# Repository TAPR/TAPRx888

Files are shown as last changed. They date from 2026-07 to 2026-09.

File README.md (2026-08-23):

# TAPRX-888

A simplified, **HF-only** software-defined radio (SDR) receiver based on the
**RX-888** — with improved thermal and RF layout.

The KiCad project lives at the repository root (`TAPRX-888.kicad_pro` /
`.kicad_sch` / `.kicad_pcb`). **KiCad 10.0** is the project baseline.

## Features

- HF-only — no VHF downconverter
- Larger PCB, 6-layer
- 0603 passive components
- Improved thermal layout
- Improved RF alias filter
- RF shelving filter (bypassable)
- External reference clock input, auto-switching
- Attenuated filter-bypass injector port (used for timesync)
- Support use of a SPI boot EEPROM, with option for USB-only or SPI boot w/ USB fallback

Please see the schematic and layout documents for details.

## Core devices

| Function | Part |
|---|---|
| ADC | LTC2208 (16-bit) |
| Clock generator | Si5351 |
| USB3 controller | EZ-USB FX3 (CYUSB301x) |
| SPI boot flash | MX25L3233F |

## Mechanicals and Enclosure Design

The project ships its own mechanical package: a JLCMC split-aluminium enclosure
(88 × 38 x 100 mm) with two custom **PCB end plates** and M3 mounting hardware.

The board's exported STEP is the EE↔ME interface; CI assembles enclosure + board +
both plates into a coloured 3D model with a self-contained browser viewer
(**<https://tapr.github.io/TAPRx888/>**). See **[mechanical/README.md](mechanical/README.md)**
for the enclosure spec, plate geometry, and fit-check flow.

## Repository & workflow

The KiCad project is at the repo root. Design/PCB, mechanical, and end-plate work
happens on the **`design`** branch (one person at a time — KiCad layout files
can't be merged); docs, CI, and tooling go on **`dev-*`** branches; flow is
`design → dev → main`. See **[CONTRIBUTING.md](CONTRIBUTING.md)** for how we
collaborate and **[docs/RELEASE_STRATEGY.md](docs/RELEASE_STRATEGY.md)** for
branches, CI, and versioning.

## Releases

CI publishes version-stamped fabrication/design packages as GitHub Releases; the
`dev` `v0.x` pre-releases also bundle the end plates, the 3D enclosure assembly,
and a live viewer (**<https://tapr.github.io/TAPRx888/>**). Grab the latest from
the **[Releases page](https://github.com/TAPR/TAPRx888/releases)**; see
**[docs/RELEASE_STRATEGY.md](docs/RELEASE_STRATEGY.md)** for details.

## Documentation

- **[mechanical/README.md](mechanical/README.md)** — the enclosure & end-plate
  package (geometry, fit-check CI, 3D viewer)
- **[CONTRIBUTING.md](CONTRIBUTING.md)** — how we collaborate (the two-lane
  `design` / infra flow, the design baton)
- **[docs/RELEASE_STRATEGY.md](docs/RELEASE_STRATEGY.md)** — versioning, CI, and
  how releases are cut
- **[docs/AI_REVIEW.md](docs/AI_REVIEW.md)** — using AI review responsibly; read
  this before pointing an AI tool at the design
- **[docs/EMERGENCY_ROLLBACK.md](docs/EMERGENCY_ROLLBACK.md)** — the parachute:
  how to turn the CI/branch machinery off if it's ever too much

## Reference documents

Device datasheets (LTC2208, Si5351, EZ-USB FX3, MX25L3233F) and RX888 reference
material are on the [project wiki → Reference Documents](https://github.com/TAPR/TAPRx888/wiki/Reference-Documents).

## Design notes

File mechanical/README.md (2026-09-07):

# Mechanical — enclosure & end plates

The TAPRX-888 mechanical package: the enclosure model and the two end-plate
boards. It lives **in this repo** (not a separate one) because the plates are
mechanically coupled to the board — a connector move and its matching cutout move
land as one atomic commit and version together.

```
mechanical/
  enclosure.step    # case model — the EE↔ME interface artifact
  endplate-front/   # standalone KiCad project (front panel)
  endplate-rear/    # standalone KiCad project (rear panel)
```

## Enclosure

`enclosure.step` — the [JLCMC split aluminium box][box] (`K70-8838-H7`, 88 × 38),
**shortened 120 → 100 mm** with the **stock end plates removed** so the PCB plates
take their place. Two-piece (both clamshell halves); verified 88 × 38.02 ×
100 mm, 2 solids. The plate outline and M3 corner pattern (Ø3.4 at ±41, ±14.21
from centre) come from its end profile.

[box]: https://jlcmc.com/product/b/U01/BR9272/aluminum-box-%28jlc%29-88*38*120mm-split

Each plate is its own KiCad project (own `fp-lib-table`/`sym-lib-table`); the root
board is untouched. The plates are **non-signal PCBs** — Edge.Cuts, connector
cutouts, mounting holes, silk (labels + TAPR/HamSCI/TIS logos), plus a
script-generated **GND shield pour + stitching-via ring, grounded to the
enclosure through the M3 screws** (see *Shield pour & GND stitching* below).

## Releases

Board and plates version separately on `main` (`vX.Y` vs independent
`endplates-vX.Y`); the `dev` `v0.x` pre-release folds board + both plates + the
mechanical assembly into one snapshot. See `docs/RELEASE_STRATEGY.md`. The board's
exported **STEP** is the EE↔ME interface, published standalone as
`TAPRX-888-v<REV>.step`.

## Fit-check CI

The reusable `mechanical-build.yml` (called by `mechanical-ci` on `design`/`dev-*`
and by `dev-release` on `dev`) assembles enclosure + board + both plates
(`assemble_mechanical.py`, CadQuery) into a multi-component STEP, a coloured GLB
(`assemble_glb.py`), and a self-contained viewer (`make_3d_viewer.py`), and
deploys the viewer to **<https://tapr.github.io/TAPRx888/>**. The viewer
(three.js) lets you toggle the four top-level parts -- enclosure, main board,
front / rear end plates -- on and off (turning the translucent enclosure off is
handy for seeing the board inside). `assemble_glb.py` recolours the boards'
soldermask to the Turn Island navy (KiCad's `Blue` stackup preset exports a
brighter cornflower blue), and the viewer's lighting is tuned so every face reads
the same colour. Non-gating; board **connector** 3D models are still missing (#45).

## Plate geometry

**Starter boards, not fab-ready** — open each in KiCad 10 to confirm it parses,
then overlay onto the enclosure end to confirm J1↔J1 / J5↔J5 orientation. Full
parameters live on each board's `Cmts.User` layer; key values:

| Item | Value |
|---|---|
| Outline | 88 × 38 mm, R4.5 |
| M3 mounting holes | Ø3.4 at (±41, ±14.21); plate screws on |
| SMA `J1/J3/J2/J4` (front) | X = −27 / −9 / +9 / +26.8, Y = 7.9; Ø7.0 |
| USB `J5` (rear, X-mirrored) | X = 25.04, Y = 14.79; 12.5 × 12.7 opening |
| JTAG `J11` | internal, no cutout |

Cutout X maps the real connector position via `plate-X = 44 + (board-X − 138)`; Y
from the 7.9 mm PCB rail height above the floor.

## Shield pour & GND stitching

Each plate carries a **dual-layer GND copper pour** (F.Cu + B.Cu, the `shield`
zone) tied together by a **perimeter ring of 0.3 / 0.6 mm through-vias**, and is
**grounded to the aluminium enclosure through the M3 screws** — each mounting hole
gets a Ø7 **exposed-copper mask aperture** on both faces so the screw/washer bites
bare ENIG copper. The **front** plate additionally gets a **Ø10 copper-pour
keepout** around each SMA. Together: an EMI shield bonded front↔back and to chassis.

The plates have **no schematic** (they're generated, PCB-only), so there is no net
list to draw a net from. Instead the pour and ring are put on a **`GND` net written
straight into the board** by `scripts/stitch_perimeter.py` (name-based net, KiCad
10 `20260206` format). That shared net is what lets the pour flood **solidly onto
the ring** instead of clearing around it; KiCad keeps the injected net across load
and DRC is clean, so no stub schematic is needed.

**All of this copper is generated — do not hand-edit it.** Retune the constants at
the top of `scripts/stitch_perimeter.py` (`INSET_MM`, `PITCH_MM`, `HOLE_KEEPOUT_MM`,
`SMA_KEEPOUT_DIA_MM`, `SCREW_MASK_DIA_MM`, drill/pad) and re-run per plate:

```sh
# front (SMA keepouts + screw grounding)
python3 scripts/stitch_perimeter.py mechanical/endplate-front/endplate-front.kicad_pcb --net GND --sma-keepout --screw-mask
# rear (screw grounding; no SMAs)
python3 scripts/stitch_perimeter.py mechanical/endplate-rear/endplate-rear.kicad_pcb  --net GND --screw-mask
```

then open in KiCad, **refill zones (`B`)**, and DRC. The script is idempotent — it
strips its own previous ring / keepouts / mask apertures before placing — derives
the outline and hole classes from the board's own Edge.Cuts, and lays the ring
**symmetric about both plate centrelines**, inset from the edge and stood off the
holes.

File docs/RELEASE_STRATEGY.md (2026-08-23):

# Release Strategy

How TAPRX-888 versions, builds, and publishes. Implemented in
`.github/workflows/` (`dev-checks`, `dev-release`, `main-release`,
`endplate-release`, `mechanical-ci`, reusable `mechanical-build`) and
`scripts/next_version.sh` (offline-tested by `scripts/test_next_version.sh`).

## Branches & CI

Flow: **`design` → `dev` → `main`**, with a `ci-docs` review surface.

- **`design`** — designer's working branch (unprotected). Each push runs
  `dev-checks` and publishes results to `ci-docs`.
- **`ci-docs`** — throwaway branch holding the latest `design` check results
  (ERC/DRC/BOM + schematic PDF), readable via `raw.githubusercontent.com`; the
  reviewer reads it to decide `design → dev`.
- **`dev`** — integration + default branch; protected. A qualifying merge cuts a
  `v0.x` **pre-release**. `dev-*` feature branches also run `dev-checks`.
- **`main`** — release branch; protected, stricter gate. `dev → main` cuts a
  production revision.

Merges into `dev` and `main` are **squash** merges. Which work goes on which
branch (design/PCB/mechanical vs docs/CI) is in `CONTRIBUTING.md`.

CI lanes:

- **`dev-checks`** — on `design`/`dev-*` pushes and PRs into `dev`/`main`: ERC,
  DRC, BOM completeness + schematic PDF / gerbers artifacts; on `design`, also
  publishes to `ci-docs`.
- **`dev-release`** — on merge to `dev`: the `v0.x` combined pre-release (below).
- **`main-release`** — on merge to `main` (or dispatch): production `vX.0`.
- **`endplate-release`** — on merge to `main`: independent `endplates-vX.Y` lane.
- **`mechanical-ci`** / reusable **`mechanical-build`** — mechanical assembly +
  Pages viewer for `design`/`dev-*` (`dev` is handled by `dev-release`).

## Versioning

**`main` = production spins (whole majors); `dev` = the minors between.** `dev`'s
major follows whatever `main` last shipped.

| Event | Version |
|---|---|
| `dev` merge, pre-1.0 | `0.6 → 0.7 …` |
| first `dev → main` | **`1.0`** |
| `dev` merge, post-1.0 | `1.1 → 1.2 …` |
| next `dev → main` | **`2.0`** |

- **`main`** = `<latest main major + 1>.0` (first ever → `1.0`); always a major,
  published as a normal Release ("Latest").
- **`dev`** = minor++ in the current major line; first after a `main` `X.0` is
  `X.1`, pre-1.0 seeds at `0.6`. Published `--prerelease`. Does **not** retire at
  1.0 — it keeps running `1.x`, `2.x`, … toward the next `main`.

**GitHub Releases are the source of truth** — no version lives in the design.
Tags `v<MAJOR>.<MINOR>`; pre-releases add a `(pre-release)` title suffix. Policy
lives once in `scripts/next_version.sh`, called by both lanes.

### `dev` combined snapshot

The `dev` pre-release is a **single combined snapshot** (unlike `main`, where
board and plates ship on separate lanes). Each qualifying `dev` merge folds into
the one `v0.x` pre-release:

- the **board** package (`scripts/build_release.sh`);
- **both end-plate** packages (`scripts/build_endplates.sh`), stamped with the
  board's `v0.x` and the end-plate design commit;
- the **mechanical assembly** — STEP + coloured GLB + self-contained 3D viewer
  (reusable `mechanical-build.yml`) — and it deploys the viewer to GitHub Pages
  (<https://tapr.github.io/TAPRx888/>).

Its trigger therefore spans board ∪ end-plate ∪ mechanical inputs
(`mechanical/**`, `3d/**`, `TAPR.kicad_wks`, the `assemble_*` / `make_3d_viewer` /
`build_endplates` scripts) — any of them cuts/refreshes it. `dev` deploys Pages
here, not via `mechanical-ci`, so the two never double-deploy.

## When is a revision cut?

Both lanes publish **only when a design file changed since the last release** (of
any kind) — compared against the last release's commit, not the merge diff, so an
earlier unpublished design edit is still caught and a later docs-only merge can't
mask it. Docs/CI/script-only merges are a no-op.

**Design files:** `*.kicad_sch`, `*.kicad_pcb`, `*.kicad_pro`, `*.kicad_dru`,
`*.kicad_sym`, `Library.pretty/**`, `fp-lib-table`, `sym-lib-table`.
**Not:** `README.md`, `docs/**`, `.github/**`, `scripts/**`, `*.kicad_prl`.
(The `dev` snapshot additionally treats `mechanical/**`, `3d/**`, `TAPR.kicad_wks`
and the assembler scripts as triggers — see above.)

## Provenance (`${REVISION}`, `${GIT_HASH}`)

**Injected at build time** (`scripts/inject_provenance.py`), never committed back
— the design's committed placeholders (`DEV`/`dev`) apply only to local opens.

- `${REVISION}` — the published version, stamped into the `rev` of every sheet
  (root + `Front_End` + `refclk`) and the board.
- `${GIT_HASH}` — the **last commit that touched a design file** (not `HEAD`), so
  the mark is stable across docs-only commits.

## Release assets

Each release attaches **version-stamped** assets (the filename names its own
version). PDFs inside `…-fabrication.zip` are stamped too.

| Asset (`v<REV>`) | Contents |
|---|---|
| `TAPRX-888-v<REV>-schematic.pdf` | Schematic |
| `TAPRX-888-v<REV>-assembly.pdf` | Assembly drawing (top + bottom, framed) |
| `TAPRX-888-v<REV>.step` | Board STEP — the EE↔ME interface |
| `TAPRX-888-v<REV>-gerbers.zip` | Gerbers + drill (JLCPCB-ready) |
| `TAPRX-888-v<REV>-fabrication.zip` | Full package: gerbers, drill, LCSC BOM, CPL, iBOM, PDFs, board STEP, stamped `VERSION.txt` |

> No fixed `releases/latest/download/<name>` path (version is in the filename) —
> link to the release page. Board STEP + 3D renders ship (models vendored in
> `3d/`, resolved via `KICAD10_3DMODEL_DIR`); board **connector** models are still
> absent (issue #45), so those parts are missing from the STEP/renders.

## End-plate lane (independent, `main`)

The end plates (`mechanical/endplate-{front,rear}`) release independently via
`endplate-release.yml` — a plate change never moves the board's `vX.Y`, or vice
versa.

- **Trigger:** on merge to `main`; publishes only when a plate dir or the shared
  `TAPR.kicad_wks` changed since the last endplates release.
- **Version:** both plates cut together; tags `endplates-v<MAJOR>.<MINOR>`, minor
  auto-increments (never rolls over), first → `endplates-v1.0`; major via dispatch
  `version:`. Numbered inline, separate from the board.
- **Build:** `scripts/build_endplates.sh` stamps provenance (empty `--sheets`,
  PCB-only) and exports per plate `endplate-<front|rear>-v<REV>-gerbers.zip` +
  `-fab.pdf`. No BOM/CPL (no components).

## Manual operation (board lanes)

`main-release` / `dev-release` take `workflow_dispatch` inputs — no YAML edits:

```sh
gh workflow run main-release.yml --ref main -f version=2.5   # force a number
gh workflow run main-release.yml --ref main -f dry_run=true  # build only, no publish
```

- **`version`** — force a number; blank = automatic. Re-running an existing
  version is **idempotent** (`gh release upload --clobber`) — the "re-publish /
  fix a release" button.
- **`dry_run: true`** — builds the full package as run artifacts
  (`release-package`), forces a build even with no design change, publishes
  nothing.
- **PR preview:** every PR into `dev`/`main` touching the design or pipeline runs
  a **forced dry-run** — download `release-package` from the PR's Checks tab. The
  `release` job is gated on `publish==true` (never set for PRs).
- **Approval gate (optional):** create an Environment `release` with a required
  reviewer and uncomment `environment: release` on the `release` job.

> The **Run workflow** button only appears once the workflow is on the default
> branch (`dev`); until then the PR preview validates the pipeline.

## Edge cases

- **First production release:** no prior non-prerelease → `v1.0` (always publishes).
- **`dev` after a `main` release:** major follows `main`, so the first pre-release
  after `1.0` is `1.1` (not `0.x`/`2.0`).
- **Doc-only merge, or `main` merge with no design change:** no-op on either lane.

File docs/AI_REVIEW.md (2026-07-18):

# Using AI review on this project

This project welcomes AI-assisted review (Claude and similar). It can be
genuinely useful. It can also confidently invent problems that don't exist and
waste everyone's time — that has already happened once on this board. This file
exists so that anyone using an AI reviewer here does it the way that helps, not
the way that misleads.

Read this before pasting the design into any AI tool and reporting what it says.

## The core rule: a finding is a lead, never a verdict

An AI model will state things about this design with total confidence, including
things that are wrong. Its sense of the netlist — what's actually wired to what —
is weak unless it has been carefully grounded first (see below). It also tends to
tell you what sounds alarming or what flatters your question.

So: treat every AI finding as a **lead to check against the real design**, not as
a result. Nothing an AI says gets reported to the team as a problem, and nothing
gets acted on, until it's been verified against the current schematic/PCB and the
closed issues. This is the same "validate findings before acting" rule in
`CONTRIBUTING.md` — it applies double to AI output.

If you can't personally verify a finding, say so when you report it: "the model
flagged X, I haven't confirmed it" — don't pass it on as fact.

## Ground the model before you trust a single word

The near-miss on this board (an AI "conclusively" reporting the FX3 power/ground
was inverted — it wasn't) happened because the model was reasoning without the
reference material. Before you ask an AI anything design-level, give it, in this
order:

1. **The datasheets** — LTC2208 (ADC), Si5351 (clock), EZ-USB FX3 / CYUSB301x
   (USB3 controller), MX25L3233F (SPI flash). On the project wiki → Reference
   Documents.
2. **The reference schematic** — the FX3 SuperSpeed Explorer Kit page and
   Infineon AN70707 (FX3 hardware design guidelines / schematic checklist). Much
   of what an ungrounded model "finds" is answered directly by these.
3. **The firmware** — https://github.com/ringof/rx888-firmware — for anything
   about how the parts are actually driven (clocking, I2C, boot).
4. **The current design** — the schematic/PCB from the repo, and
5. **The closed issues** —
   https://github.com/TAPR/TAPRx888/issues?q=is%3Aissue+state%3Aclosed Closed
   issues are already-fixed items. An ungrounded model will "rediscover" them as
   new problems. Always check a finding against the closed list first.

An AI that hasn't been given these is not reviewing the board — it's guessing
about a board.

## How to actually run a useful review (the method)

This is roughly the workflow that has produced good results here:

1. **Prime it** with the material above — datasheets, design intent, firmware,
   and the combined netlist/schematic — before asking for findings.
2. **Expect the first pass to be poor and challenge it.** Don't accept the
   opening answer; push back, ask it to trace the actual net, ask how it knows.
3. **Distill.** Its raw output is feedstock, not conclusions. Pull out the claims
   worth checking, verify each against the real design and the closed issues, and
   only then do you have something worth a team issue.
4. **File verified findings as normal issues** — one item each, "clear is kind,"
   with the datasheet/appnote link that backs it (see `CONTRIBUTING.md`). File
   them as your findings that you've checked, not as "the AI said."

## For newcomers specifically

If you're new here and excited to point an AI at the design: great, but please —
its confident tone is not evidence. The failure mode is not subtle and it has
already cost this project real review cycles. A model with the datasheets and the
closed-issue list is a helpful second set of eyes. A model without them will
generate authoritative-sounding, worrying, wrong reports. The difference is
entirely in the grounding you give it and the checking you do after. Do both, or
don't report the output.

## What AI is genuinely good for here

Not to be all warnings — it's real help when grounded: sanity-checking pinouts
against a datasheet you've also handed it, drafting issue text, cross-referencing
an app-note requirement, explaining an unfamiliar part of the FX3 boot flow,
generating BOM/tooling scripts. The pattern that works is "help me check a
specific thing I can then verify," not "tell me what's wrong with this board."

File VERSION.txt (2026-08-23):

TAPRX-888  —  HF-only SDR receiver (RX-888 derivative)

Version:  development snapshot

This file names the version of the SOURCE PROJECT in this folder, so a copy
passed around as a .zip is never anonymous. The working tree is always a
development snapshot — released fabrication packages carry their exact version
on this line instead (stamped at build time).

The authoritative, fabricated revisions — each stamped with its commit hash on
the bottom silkscreen and in every exported PDF — are published here:

    https://github.com/TAPR/TAPRx888/releases

Versioning: production releases are whole majors (v1.0, v2.0, ...); v0.x and the
minor increments between majors are dev pre-releases.  See docs/RELEASE_STRATEGY.md.

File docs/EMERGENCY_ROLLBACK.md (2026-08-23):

# Emergency Rollback — read this first

The parachute. Turns off the CI/branch machinery and returns the repo to a plain
"one branch, push whenever" state. You can do all of this yourself — no waiting.

---

## READ THIS ONE LINE BEFORE YOU PULL THE CORD

**Do not roll back in the middle of a release.**

Between "cut a release" and "the boards / ADCs are actually ordered," the CI
fabrication gate is the only thing checking the package the money rides on.
Rolling back in that window removes that check. If you're in a release cycle and
something's on fire, **stop and call David** instead.

Any other time — normal design work, general frustration — roll back freely.
Nothing below is destructive to the design; schematic, PCB, libraries, and full
Git history are all preserved either way.

---

## The rollback is two steps, in two different places

Part of the "off switch" is a **file** in the repo, part is a **repo setting** on
GitHub. Deleting the file doesn't fully do it — that's expected.

### Step 1 — Stop CI (delete one folder). Anyone can do this.

Delete the `.github/workflows` folder and commit.

- GitHub Desktop: delete the folder locally, commit "Disable CI", push.
- github.com: open `.github/workflows`, delete each file, commit.

The moment that folder is gone, **CI stops running** — no more ERC/DRC/BOM checks,
no generated documents. Design files untouched.

> If a push to `design` or `dev` still kicks off a run afterward, that branch
> still carries its own copy of `.github/workflows`. To remove it from every
> branch at once, see the workflow-deletion steps in `docs/TAPR_manual_mode.md`.

If all you wanted was to make the automation stop, **you're done here.**

### Step 2 — Return to "push straight to main" (remove branch protection). Admin only.

Branch protection is a **repo setting**, not a file, so Step 1 doesn't remove it.
While protection is on you still can't push directly to `main` or `dev`.

1. **Settings → Branches** (in the TAPR/TAPRx888 repo).
2. Under "Branch protection rules," find the **`main`** rule → trash/delete → confirm.
3. Same for the **`dev`** rule.

Direct pushes to `main` work again. You can now treat `main` as the only branch
and ignore `dev` and `design`.

George has admin and can do this. David can help — a ~5-minute call — but you
don't need to wait on anyone.

---

## What this does NOT do (on purpose)

- Does **not** delete any branches, design files, or history. `dev` and `design`
  still exist; you just aren't forced through them.
- Does **not** tell you how to set the structure back up. Rebuilding CI + branch
  protection is the fiddly part — do it deliberately, together with David, not as
  an emergency.

---

## One-paragraph summary

CI machinery = the `.github/workflows` folder; delete it, CI stops. Branch
protection = a setting under Settings → Branches; remove the `main` and `dev`
rules and you're back to pushing straight to `main`. Safe anytime **except
mid-release**, where you call David instead. Nothing here touches the design or
its history.

---

## Related

- **Keep the branches, run checks/releases by hand:** `docs/TAPR_manual_mode.md`.
- **Undo the whole migration:** `docs/TAPR_rollback.md`.

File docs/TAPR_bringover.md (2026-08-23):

# TAPR bring-over runbook — migrating ringof's work into TAPR

**Purpose.** The forward migration, mirror of `docs/TAPR_rollback.md`. Brings
ringof's flattened design + CI/versioning/docs onto **TAPR/TAPRx888** as the
canonical repo via the **replay-on-top-of-`c01bece8`** model: one migration
commit, `main` advances by **fast-forward** (no force-push), `c01bece8` stays a
real ancestor so rollback is trivial.

Cross-refs: `docs/TAPR_rollback.md` (undo), `docs/TAPR_manual_mode.md`
(de-automate but keep the flow).

---

## What we're bringing, and why it's safe

- **Design is materially identical.** TAPR's `c01bece8` and ringof's `dev` share
  ancestor `3fb7ab5`; the design files (`.kicad_pcb/.sch/.pro`) differ by only
  ~5–9 lines each — ringof's provenance edits (silkscreen / `REPO` / rev), not
  electrical change.
- **ringof fixes the folder mess.** `c01bece8` still carries the old
  `TAPRX-888 KiCad/` **and** `TAPRX-888 KiCad - Copy/` duplicate directories;
  ringof's tree is **flattened to the repo root** and adds CI, scripts, docs.
- **Histories diverge**, so this is not a merge — replay ringof's tree as one
  commit whose parent is `c01bece8`.

## Readiness (already true on ringof `dev`)

- **Tree is TAPR-ready — no content edits at migration time.** De-ringofed
  (`REPO` → `github.com/TAPR/TAPRx888`, wiki/release links → TAPR); workflows use
  `${GITHUB_REPOSITORY}`; `VERSION.txt` de-numbered. The only literal "ringof"
  strings left are in these runbook docs.
- **CI is proven** green end-to-end in ringof.

---

## Settled decisions

1. **First `v1.0` is deferred — the migration is quiet.** Releases are per-repo,
   so TAPR starts with zero. Leaving Actions on while seeding would auto-cut a
   `v0.6` pre-release (first `dev` push) and a `v1.0` (first `main` push), so
   **seed with Actions disabled** (step 1); cut the first real `v1.0` later
   (step 8).
2. **Legacy PRs #4 and #30 are already closed.** Their `refs/pull/{4,30}/head`
   refs linger but are harmless — they target the pre-flatten `main` and stay
   closed.

---

## Repo settings to set on TAPR (once)

- **Settings → Actions → General → Workflow permissions → Read and write.** The
  `ci-docs` publish step and release jobs push via the built-in `GITHUB_TOKEN`;
  the default read-only token would fail them. No external secrets needed.

---

## Dry-run rehearsal (do it once, in a throwaway repo)

Rehearses the **seeding sequence** against a `c01bece8`-shaped repo.

```sh
# 1. Create an empty scratch repo (GitHub UI, or: gh repo create you/tapr-mige --private)
git remote add scratch https://github.com/<you>/tapr-mige.git
# 2. Seed it with TAPR's current state:
git push scratch tapr/main:main
# 3. Run steps 0–7 below against 'scratch' instead of 'tapr'. Watch dev-checks go
#    green, ci-docs populate, and (optionally) a release cut. Then test the
#    rollback runbook against it.
# 4. Delete the scratch repo when satisfied.
```

---

## The live bring-over

Work from a local clone with **both** remotes:

```sh
git remote -v      # origin -> ringof/TAPRx888 ; tapr -> TAPR/TAPRx888
git fetch tapr origin --tags
```

### 0. Anchor first — the restore point (see TAPR_rollback.md, step zero)

```sh
TAG="pre-migration-$(date +%Y-%m-%d)"
git tag -a "$TAG" tapr/main -m "TAPR state before the ringof bring-over"
git push tapr "$TAG"
git push tapr tapr/main:refs/heads/pre-migration    # human-friendly restore branch
```

### 1. Disable Actions (so seeding pushes don't fire CI / cut releases)

Settings → Actions → General → **Disable actions**. Re-enabled in step 6.

### 2. Build the migration commit (tree = ringof `dev`, parent = `c01bece8`)

```sh
MIG=$(git commit-tree "$(git rev-parse origin/dev^{tree})" -p tapr/main \
      -m "Bring over ringof: flatten to repo root; add CI, versioning, docs")
git branch -f dev "$MIG"
git diff --quiet origin/dev dev && echo "dev tree == ringof/dev ✓"
```

Working-tree equivalent, if you prefer:

```sh
git checkout -B dev tapr/main
git rm -rq .
git checkout origin/dev -- .
git commit -m "Bring over ringof: flatten to repo root; add CI, versioning, docs"
```

### 3. Push the branches to TAPR

```sh
git push tapr dev:dev       # new branch
git push tapr dev:main      # FAST-FORWARD c01bece8 -> migration commit (no --force)
git push tapr dev:design    # new branch (the designer's working branch)
```

(`ci-docs` is created automatically by the first `design`-push CI run — do not
seed it by hand.)

### 4. Set the default branch

Settings → General → **Default branch → `dev`**.

### 5. Turn on branch protection

- **`dev`** — require a PR; block force-push and deletion.
- **`main`** — same, as the stricter release gate.
- **`design`** — **no protection**.

(Added *after* the seeding pushes so it doesn't block them.)

### 6. Re-enable Actions

Settings → Actions → General → enable. Nothing fires from this alone: seeding
happened with Actions off, and all branches sit at the migration commit.

### 7. Smoke test — prove the live flow, low-stakes

Push a trivial **non-design** change (e.g. a doc typo) to `design`:

```sh
git switch design && git pull
# edit any doc
git commit -am "smoke test: confirm CI on TAPR" && git push
```

Confirm: `dev-checks` runs **green**, and **`ci-docs`** is created with the review
set (`erc.rpt`, `drc.rpt`, `bom.csv`, `bom_check.txt`, schematic PDF). No release
is cut (not a design file).

### 8. First real release — when the team is ready (deliberate)

Merge `design → dev` for the first pre-release, then `dev → main` (or dispatch
`main-release`) for **`v1.0`** production. See `docs/RELEASE_STRATEGY.md`.

---

## Verification — TAPR is migrated

- **Branches:** `main`, `dev`, `design`, `ci-docs` (+ `pre-migration` anchor,
  + any surviving PR refs).
- `git fetch tapr && git diff --quiet origin/dev tapr/dev && echo "dev == ringof/dev ✓"`
- **`main` is a fast-forward child of the restore point:**
  `git merge-base --is-ancestor c01bece8 tapr/main && echo "c01bece8 is an ancestor ✓"`
- **Default branch** = `dev`; **protection** = dev+main protected, design open.
- **Actions** green; **`ci-docs`** populated.

## If it goes wrong

Use `docs/TAPR_rollback.md`. Because `main` only **fast-forwarded**, the reverse
is clean: reset `main` back to the `pre-migration` anchor and delete
`dev` / `design` / `ci-docs`.

---

## Why this order

- **Anchor before touching anything** → pre-migration state is unloseable.
- **Actions off during seeding** → no surprise `v0.6`/`v1.0` from seed pushes.
- **Protection after the pushes** → protection would otherwise block seeding.
- **`main` by fast-forward, not force** → history stays continuous, rollback stays
  a one-liner.

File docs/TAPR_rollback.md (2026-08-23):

# TAPR rollback runbook — undoing the ringof bring-over

**Purpose.** The bring-over restructures **TAPR/TAPRx888**: moves `main`, adds
`dev`, `design`, `ci-docs`, installs CI workflows, turns on branch protection.
This runbook restores TAPR to its **exact pre-migration state**.

> **This doc lives in ringof on purpose.** Rolling TAPR back deletes any copy
> stored on TAPR itself; ringof keeps the whole history (and the ability to retry).

---

## The restore point

Before the bring-over, TAPR is a **single-branch repo**:

```
tapr/main → c01bece8f9f490c37a96d8cb2675cc290c8f881a   ("proper update")
```

- No `dev`, `design`, or `ci-docs` branches.
- No CI workflows, no GitHub Releases, no version tags.
- Two open pull requests (**#4**, **#30**) predate the migration; neither
  bring-over nor rollback touches them.

Captured with `git ls-remote https://github.com/TAPR/TAPRx888` on 2026-07-18.
Re-confirm the SHA before relying on it — if `main` has moved, the current tip is
the real restore point and the anchor below must be re-cut.

---

## Step zero — anchor BEFORE the bring-over (always do this first)

The migration's very first action, *before any branch is moved*, is to make the
current state unloseable. A tagged commit is immutable and never GC'd, so the
pre-migration state is always one reset away.

```sh
# From a local clone that has the TAPR remote (here called "tapr"):
git fetch tapr
TAG="pre-migration-$(date +%Y-%m-%d)"          # e.g. pre-migration-2026-07-18
git tag -a "$TAG" c01bece8 -m "TAPR state before the ringof CI/branch bring-over"
git push tapr "$TAG"

# Recommended: also a human-friendly restore BRANCH at the same commit.
git push tapr c01bece8:refs/heads/pre-migration
```

Record once done:

- Anchor tag: `pre-migration-YYYY-MM-DD` → `c01bece8…`
- Anchor branch: `pre-migration` → `c01bece8…`

---

## The reverse procedure

Run **only** if TAPR abandons the workflow. Every destructive step needs TAPR
admin. Do them in order.

### 1. Lift branch protection

Settings → **Branches / Rulesets** → disable or delete the rules on `dev` and
`main`. A protected branch cannot be force-moved or deleted, so this comes first.

### 2. Reset `main` to the restore point

```sh
git fetch tapr
git push --force tapr pre-migration:main        # from the anchor branch
# or, equivalently, straight from the SHA:
# git push --force tapr c01bece8:main
```

Verify: `git ls-remote tapr refs/heads/main` → `c01bece8…`.

### 3. Delete the branches the bring-over added

```sh
git push tapr --delete dev design ci-docs
```

(If a CLI delete is blocked, do it from the GitHub UI: **Branches → trash icon**.)

### 4. Confirm CI and protection are gone

- Resetting `main` to `c01bece8` removes the workflow files (absent in that
  commit), so **Actions** shows no workflows once `design`/`dev` are also gone.
- Delete any remaining branch-protection rules from the trial.
- Keep the `pre-migration` tag/branch if a retry is possible.

### 5. Purge trial artifacts (Releases + their tags)

The trial cuts board releases (`v0.x` pre-releases, `v1.0` if production was cut)
**and** independent end-plate releases (`endplates-vX.Y`, published on `main` by
`endplate-release.yml`). Remove both for a clean slate:

```sh
gh release list --repo TAPR/TAPRx888
# Board releases (delete the tag too):
gh release delete v0.6 --repo TAPR/TAPRx888 --cleanup-tag --yes
# repeat for v0.7, v0.8, …, and v1.0 if present
# End-plate releases:
gh release delete endplates-v1.0 --repo TAPR/TAPRx888 --cleanup-tag --yes
# repeat for every endplates-v* release/tag
```

(Or **Releases** page → each release → **Delete**, then delete leftover tags
under **Tags** — including any `endplates-v*`.)

---

## Verification — TAPR is back where it started

- `git ls-remote tapr` shows only: `main = c01bece8…`, the open PR refs (#4,
  #30), and — if kept — the `pre-migration` anchor. No `dev` / `design` / `ci-docs`.
- **Actions** tab: no workflows.
- **Releases**: none from the trial (no `v*` and no `endplates-v*`).
- `git fetch tapr && git diff c01bece8 tapr/main` → **empty**.

---

## What rollback does NOT undo

- **Clones/forks made during the trial** keep their copies.
- **ringof is untouched** — a second attempt is possible.
- **Open PRs #4 and #30** are left as they were.

---

## Retrying later

A second attempt is just re-running the bring-over from ringof. **Re-cut a fresh
`pre-migration-<date>` anchor first** (Step zero) — the SHA differs if TAPR's
`main` moved.

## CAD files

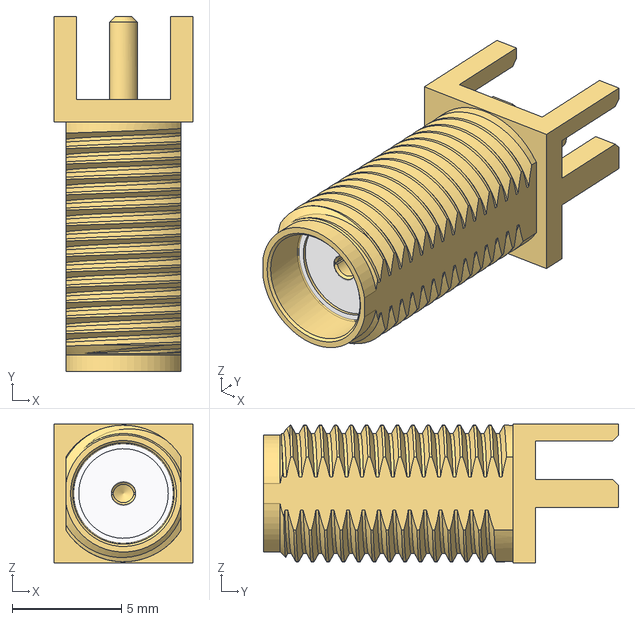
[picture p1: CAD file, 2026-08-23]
3d/SMA_Jack_EdgeMount_JLC.step
6.35 x 16.3 x 6.35 mm

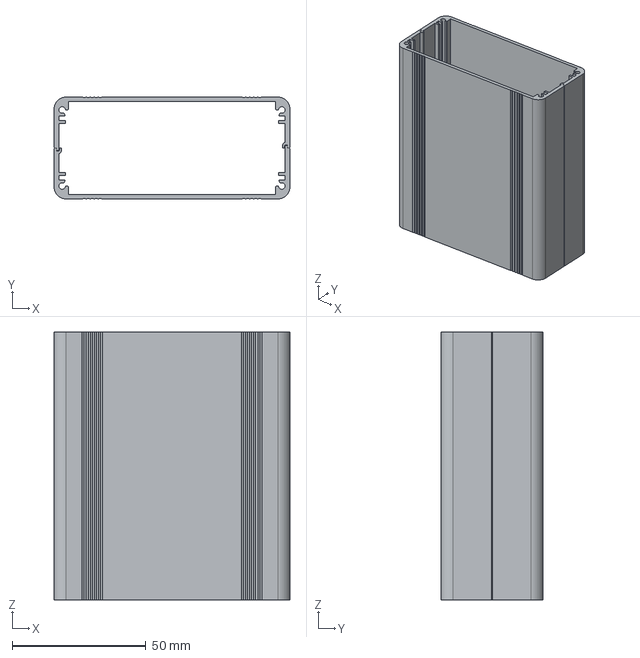
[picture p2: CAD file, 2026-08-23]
mechanical/enclosure.step
88.0 x 38.0 x 100.0 mm
enclosure_100mm_extrusion_1
enclosure_100mm_extrusion_2

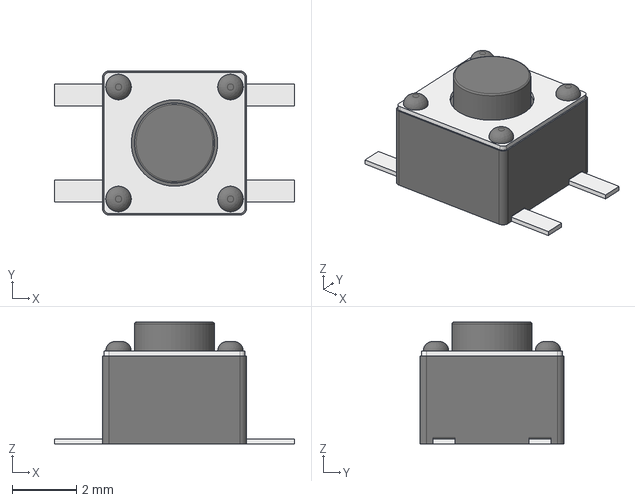
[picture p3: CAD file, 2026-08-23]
3d/BUTTON-4p5X4p5.step
7.50 x 4.50 x 3.80 mm
housing
pins x 4

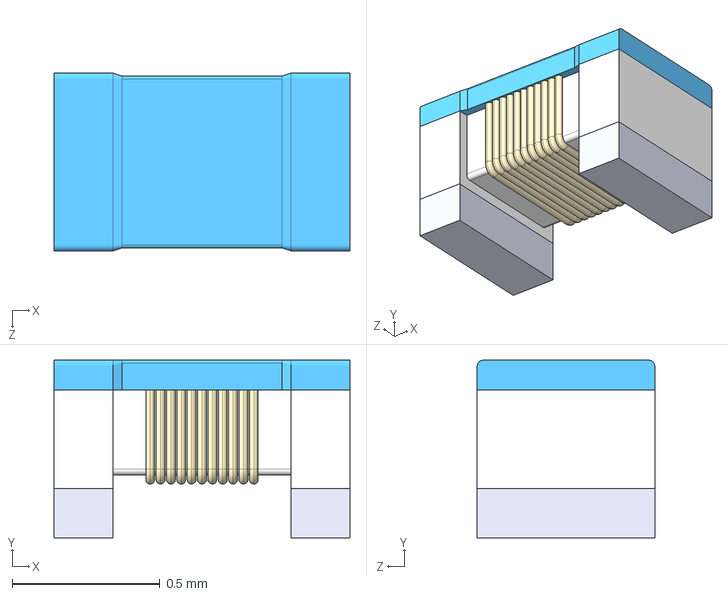
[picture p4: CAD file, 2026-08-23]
3d/Murata2U.step
1.00 x 0.6 x 0.6 mm

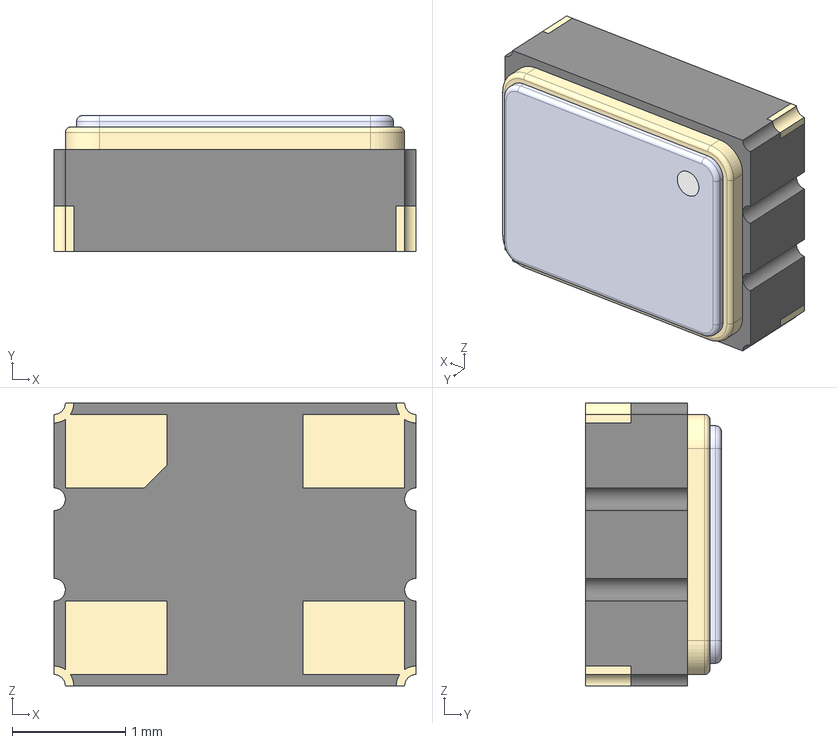
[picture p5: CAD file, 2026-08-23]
3d/TCXO-3225.step
3.20 x 1.20 x 2.50 mm
TCXO-3225-001
TCXO-3225-002
TCXO-3225-003
TCXO-3225-004
TCXO-3225-005
TCXO-3225-006
TCXO-3225-007
TCXO-3225-008
TCXO-3225-009

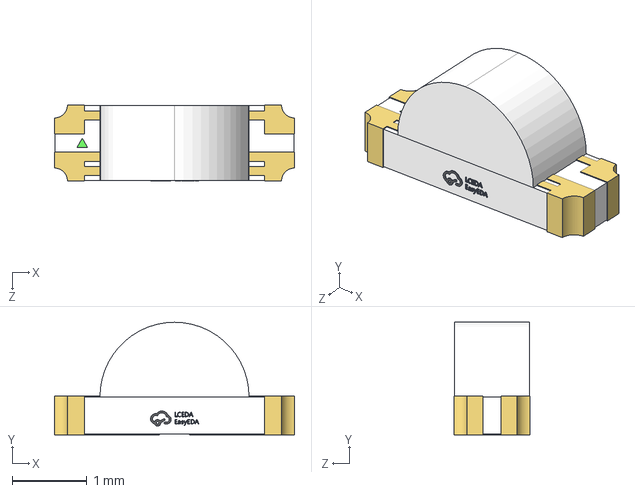
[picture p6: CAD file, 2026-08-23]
3d/LED_RGB_SIDE.step
3.22 x 1.51 x 1.02 mm

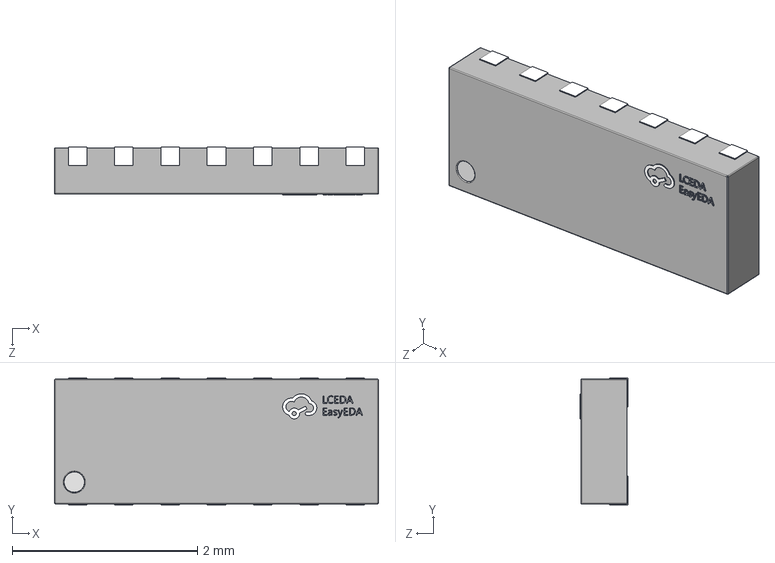
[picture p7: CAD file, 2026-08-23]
3d/SP3011.step
3.50 x 1.37 x 0.52 mm

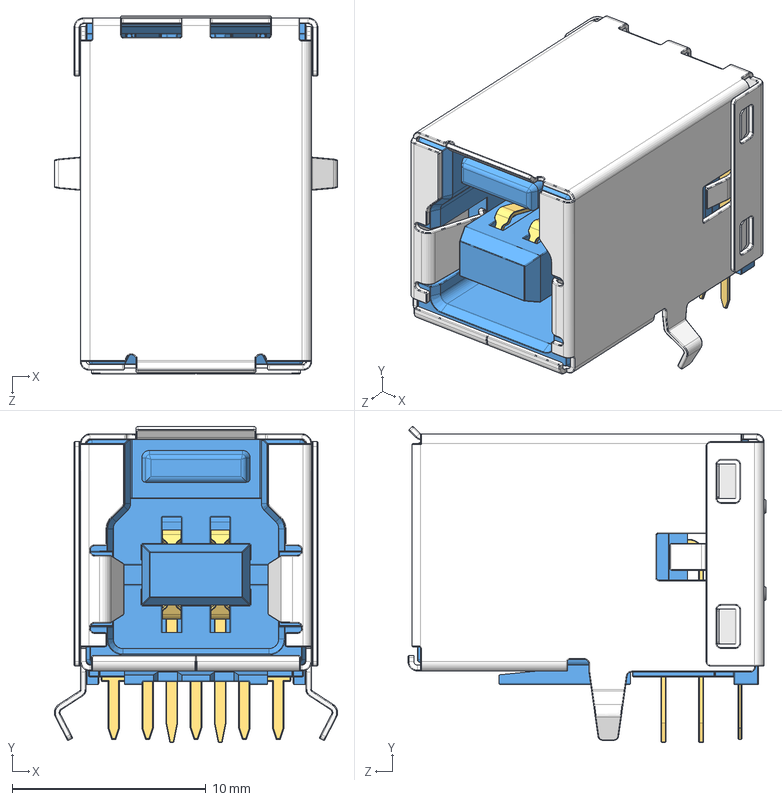
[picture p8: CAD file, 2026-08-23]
3d/USB-3.0.step
14.6 x 16.3 x 18.5 mm
inside main_ﾄｬﾈﾏｨｨ_
lower part_ﾄｬﾈﾏｨｨ_
Pin11_默认è_ x 2
Pin12_默认è_ x 2
top part_默认è_
Pin21_默认è_
out layer_ﾄｬﾈﾏｨｨ_

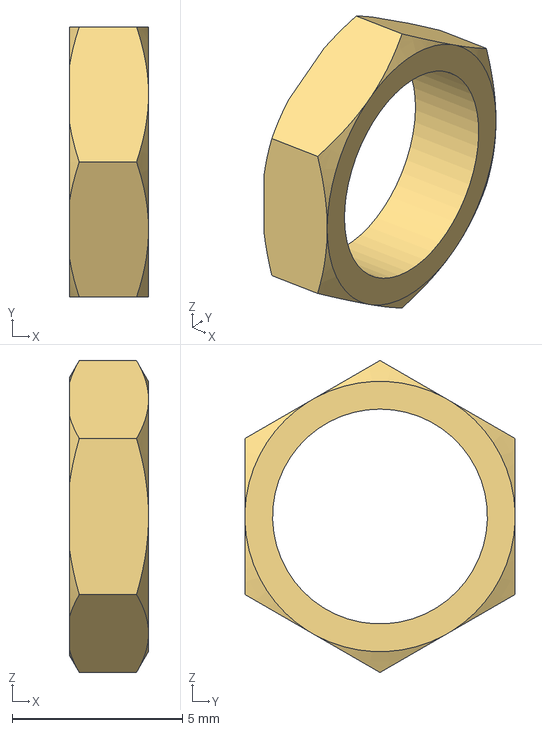
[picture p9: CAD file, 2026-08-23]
mechanical/hardware/nut.step
2.32 x 7.92 x 9.15 mm

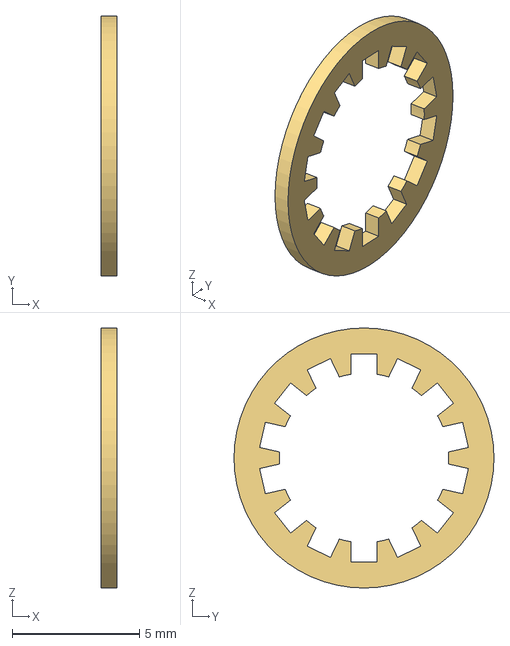
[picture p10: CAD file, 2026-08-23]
mechanical/hardware/washer.step
0.63 x 10.2 x 10.2 mm

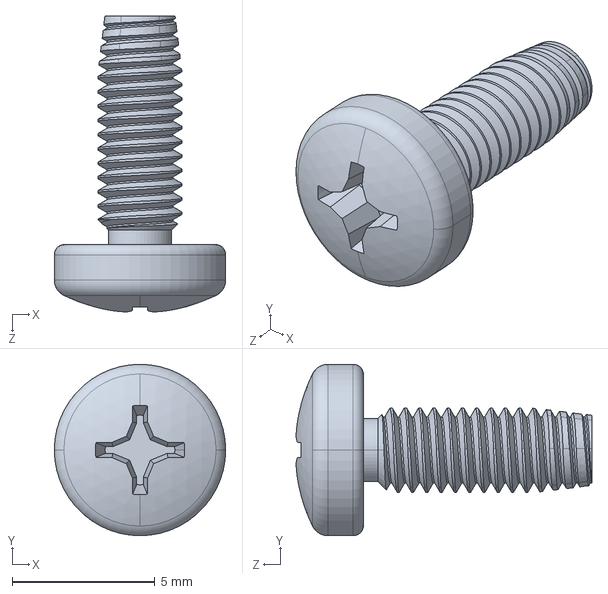
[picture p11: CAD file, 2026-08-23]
mechanical/hardware/screw-M3-threadforming.step
6.00 x 6.00 x 10.4 mm

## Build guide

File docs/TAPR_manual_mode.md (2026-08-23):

# TAPR manual-mode runbook — keep the 3-tier flow, turn CI off

**Purpose.** The middle path between *keep full CI* and *roll all the way back*
(`docs/TAPR_rollback.md`): turn the robots off but keep the `design → dev → main`
structure and hand the **same tools** to a human. Branches, design, and scripts
all stay — only the workflow automation goes.

> The automation is **only the six workflow YAML files**. Everything they call
> (`run_checks.sh`, `build_release.sh`, `next_version.sh`, `inject_provenance.py`,
> `build_endplates.sh`, `assemble_mechanical.py`, `assemble_glb.py`,
> `make_3d_viewer.py`, the KiBot config) are standalone hand-tools. Turning CI off
> just stops the robots; re-enabling is restoring six files.

Throughout, **`origin` = the TAPR repo**.

---

## What changes

**Remove** (the automation):

- `.github/workflows/dev-checks.yml`
- `.github/workflows/dev-release.yml`
- `.github/workflows/main-release.yml`
- `.github/workflows/mechanical-ci.yml`
- `.github/workflows/mechanical-build.yml`
- `.github/workflows/endplate-release.yml`
- the **`ci-docs`** branch (produced by CI; goes stale with nothing publishing to it)

**Keep** (now operated by hand):

- Branches **`design → dev → main`** — untouched.
- `scripts/*` — the manual toolkit (see *Operating the flow by hand*), including
  `run_checks.sh`, `build_release.sh`, `next_version.sh`, `inject_provenance.py`,
  `build_endplates.sh`, `assemble_mechanical.py`, `assemble_glb.py`,
  `make_3d_viewer.py`. Run these by hand instead of on push.
- `fabrication-toolkit-options.json` — JLCPCB export straight from the KiCad
  Fabrication Toolkit plugin GUI, no command line.
- `TAPR.kicad_wks`, `VERSION.txt`, the design files, and the docs.

**Branch protection:** **`main` only** — releases stay safe; `dev` and `design`
left open for day-to-day work.

---

## The switch-off procedure (needs TAPR admin)

1. **Delete the workflow files.** They must be gone on *every* branch that could
   trigger them (`design`, `dev`, `main`), or Actions still fires from whichever
   branch carries one. Remove on `dev`, then propagate by the normal merges.

   ```sh
   git switch dev && git pull
   git rm .github/workflows/dev-checks.yml \
          .github/workflows/dev-release.yml \
          .github/workflows/main-release.yml \
          .github/workflows/mechanical-ci.yml \
          .github/workflows/mechanical-build.yml \
          .github/workflows/endplate-release.yml
   git commit -m "Turn CI off; operate the 3-tier flow manually (docs/TAPR_manual_mode.md)"
   git push origin dev
   # then carry it to main and design:
   #   merge dev -> main (removes them from main)
   #   sync design up to dev (removes them from design)
   ```

2. **Delete the `ci-docs` branch:**

   ```sh
   git push origin --delete ci-docs
   ```

3. **Set protection to `main`-only:** Settings → Branches / Rulesets → remove the
   `dev` (and any `design`) rules; keep the `main` rule (require a PR, block
   force-push and deletion).

4. **(Optional, belt-and-suspenders)** Settings → Actions → General → **Disable
   Actions** for the repo, so nothing runs even if a stray workflow reappears.

---

## Operating the flow by hand

### Designer — unchanged

Pull `design`, edit in KiCad, commit, push to `design`, say "design is free."

### Reviewer — check a design change *(replaces `dev-checks` / `ci-docs`)*

```sh
git switch design && git pull
scripts/run_checks.sh          # ERC + DRC + BOM completeness -> reports/
# read reports/erc.rpt, reports/drc.rpt, reports/bom_check.txt, reports/*.pdf
```

If it looks good, merge `design → dev` (`dev` is unprotected in this mode), then
sync `design` back up to `dev` when the baton is free.

### Cut a release *(replaces `dev-release` / `main-release`)*

```sh
git switch main && git pull            # or dev, for a pre-release
REV=1.0                                # pick the number (next_version.sh can suggest it)
# GIT_HASH = last commit that touched a design file (same rule CI used):
GIT_HASH=$(git log -1 --format=%h -- '*.kicad_sch' '*.kicad_pcb' '*.kicad_pro' \
             '*.kicad_sym' 'Library.pretty' fp-lib-table sym-lib-table)

REVISION=$REV GIT_HASH=$GIT_HASH scripts/build_release.sh    # -> out/

( cd out && zip -qr "../TAPRX-888-v$REV-fabrication.zip" . )
gh release create "v$REV" "TAPRX-888-v$REV-fabrication.zip" \
  --repo TAPR/TAPRx888 --title "v$REV" \
  --notes "Fabrication package for v$REV (design commit $GIT_HASH). Built manually."
```

`build_release.sh` injects provenance and stamps `VERSION.txt`, producing the
**same stamped outputs** CI did. It needs the same tools locally (`kicad-cli`,
`kibot`, `python3`, `ghostscript`/`poppler-utils`); easiest is the same public
image:

```sh
docker run --rm -v "$PWD":/ws -w /ws \
  -e REVISION=$REV -e GIT_HASH=$GIT_HASH \
  ghcr.io/inti-cmnb/kicad10_auto:1.9.0-6_k10.0.4_d13.2 \
  scripts/build_release.sh
```

### End plates *(replaces `endplate-release`)*

Cut the independent `endplates-vX.Y` package by hand with `scripts/build_endplates.sh`
(uses `inject_provenance.py`), then `gh release create endplates-v$REV …`.

### Mechanical fit-check *(replaces `mechanical-ci` / `mechanical-build`)*

Build the assembly STEP + GLB + viewer by hand:
`scripts/assemble_mechanical.py`, `scripts/assemble_glb.py`,
`scripts/make_3d_viewer.py`.

### Fab outputs with no command line

The JLCPCB Fabrication Toolkit KiCad plugin reads
`fabrication-toolkit-options.json`, so a maintainer can export gerbers / BOM /
CPL straight from KiCad's GUI.

---

## Docs to touch when switching

- `docs/RELEASE_STRATEGY.md` and `CONTRIBUTING.md` describe the *CI-driven* flow.
  Add a "manual mode" note (or trim the CI sections) so they say checks and
  releases are run by hand via `scripts/`.
- `VERSION.txt` is already de-numbered; in manual mode you get the stamp by
  running `build_release.sh` yourself.

---

## Turning CI back on

Restore the six workflow files from history, push to `dev`, re-add `dev`
protection. The scripts never left, so CI and manual mode use the same tooling.

---

## What this does NOT do

- It does **not** touch the design or the branch structure — only the automation.
- It is **not** a rollback to pre-migration (that's `docs/TAPR_rollback.md`).
- Existing GitHub Releases are left as they are.

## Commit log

2026-07-16 proper update
    [Front_End.kicad_sch, TAPRX-888.kicad_pcb, TAPRX-888.kicad_sch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]
2026-07-18 Bring over ringof: flatten to repo root; add CI, versioning, docs
    [Front_End.kicad_sch, TAPRX-888.kicad_pcb, TAPRX-888.kicad_sch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]
2026-07-26 Bring over ringof/dev (tranche 2, stage 1): design, library, 3D, board CI & docs
    [BUTTON-4p5X4p5.step, Front_End.kicad_sch, LED_RGB_SIDE.step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]
2026-07-26 Bring over ringof/dev (tranche 2, stage 2): mechanical enclosure + 3D viewer
    [enclosure.step, endplate-front.kicad_pcb, endplate-rear.kicad_pcb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]
2026-07-28 Improved 3D viewer (#59)
    * mechanical: give the end plates a Blue soldermask stackup
    The end-plate PCBs had no physical stackup, so KiCad exported them with the
    default green soldermask. Add a 2-layer stackup with front/back mask set to the
    named "Blue" preset, summing to the existing 1.6 mm so board thickness / fit is
    unchanged. This makes the plates export blue-dominant so the viewer's soldermask
    recolour treats them the same as the main board.
    * feat(viewer): part toggles, upright orientation, Turn Island navy, even lighting
    Grow the mechanical fit-check viewer into an interactive, correctly-coloured one:
    - Part toggles: show/hide enclosure, main board, front/rear end plate. Rebuilt o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
    [endplate-front.kicad_pcb, endplate-rear.kicad_pcb]
2026-07-29 fix BAV99 value, TIS exclude from BOM
    [Front_End.kicad_sch, TAPRX-888.kicad_sch, refclk.kicad_sch]
2026-07-29 Reconcile library/schematic/board drift (ERC/DRC clean at full severity)
    Full-severity ERC/DRC surfaced 22 lib_symbol_mismatch + 5 lib_footprint_mismatch
    warnings from cached copies drifting off the library master. Reconciled and
    verified against the schematic and board:
    - Symbol caches: refresh 8 cap/diode symbols whose embedded footprint field was
    stale (PAD_0603 -> C_0603); instances and PCB already used C_0603.
    - SMA (J1-J4): push the board's tuned 3D-model offset/rotate into the library
    master and re-save it in KiCad 10 format; fix J1 LCSC C2874826 -> C914558 in
    schematic and board (J1 was an error, not a variant).
    - U.FL (J10): re-save library footprint in v10 to match the route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
    [Front_End.kicad_sch, TAPRX-888.kicad_pcb, TAPRX-888.kicad_sch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]
2026-07-29 fix orientation error for J1-J4
    [TAPRX-888.kicad_pcb]
2026-07-30 Nudge different-net vias to meet JLC 0.5mm hole-to-hole
    [TAPRX-888.kicad_pcb]
2026-07-30 Fix SC-70-6 mask slivers; min-web 0.1mm; error-clean DRC
    [TAPRX-888.kicad_pcb]
2026-07-31 interim silkscreen warning-level DRC violations cleanup
    [TAPRX-888.kicad_pcb]
2026-07-31 interim silkscreen warning-level DRC violations cleanup pt. 2
    [TAPRX-888.kicad_pcb]
2026-08-02 interim commit detailed silk/footprint clearance rules, beginning of uVia to regular drill transition
    [TAPRX-888.kicad_pcb]
2026-08-02 enable missing courtyard as 'warning' AND set logos as exempt from courtyard requirement
    [TAPRX-888.kicad_pcb]
2026-08-02 fix U19 3D model alignment
    [TAPRX-888.kicad_pcb]
2026-08-02 fix X1 3D model alignment
    [TAPRX-888.kicad_pcb]
2026-08-02 fix D3 3D model alignment
    [TAPRX-888.kicad_pcb]
2026-08-02 1-6 uVia to std via transition pt 2
    [TAPRX-888.kicad_pcb]
2026-08-02 refdes and silk cleanup, now produces a zero ERC/DRC error, zero DRC warning output
    [TAPRX-888.kicad_pcb]
2026-08-03 last cleanup of refdes, addition of USB3, USB2 net classes for DRC checks on PCB
    [TAPRX-888.kicad_sch]
2026-08-06 initial USB2/3 tweaks
    [TAPRX-888.kicad_pcb, TAPRX-888.kicad_sch]
2026-08-16 USB2/3 tweaks pt.2
    [BUTTON-4p5X4p5.step, Front_End.kicad_sch, LED_RGB_SIDE.step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]
2026-08-16 USB2/3 tweaks pt.3
    [TAPRX-888.kicad_pcb]
2026-08-16 USB2/3 diff designs rules and PCB design passing them complete
    [TAPRX-888.kicad_pcb]
2026-08-21 clean up USB pin driver ERC errors by changing non-functional pins to passive, functional to bidirectional
    [TAPRX-888.kicad_sch]
2026-08-21 remove specific callout of SPI eeprom installation
2026-08-21 tweak SPI eeprom language, again
2026-08-22 fix duplicated #PBF in LTC2208 MPN
    [TAPRX-888.kicad_pcb, TAPRX-888.kicad_sch]
2026-08-22 added a 'close enough' LCSC PN for a 10 pin JTAG header for completeness
    [TAPRX-888.kicad_pcb, TAPRX-888.kicad_sch]
2026-08-22 reselect L10/L11 120 nH to LCSC C703706 Murata 2% variant (was 5% variant) as original is no longer stocked
    [Front_End.kicad_sch, TAPRX-888.kicad_pcb]
2026-08-22 added fabrication specification on User.Comments, will be used in a layer docs output change
    [TAPRX-888.kicad_pcb]
2026-08-22 fixed wonky 'DNP' usage for removing 3D models for TP, now they are just via TP
    [TAPRX-888.kicad_pcb, TAPRX-888.kicad_sch, refclk.kicad_sch]
2026-08-22 localize stock 3D models to project (${KIPRJMOD}/3d/kicad-stock)
    The 22 stock-package 3D models resolved through ${KICAD10_3DMODEL_DIR},
    which locally points at each machine's KiCad install
    (/usr/share/kicad/3dmodels) and only in CI at the vendored
    3d/kicad-stock mirror. Same reference, different files per environment --
    and since a footprint's (rotate) compensation is only valid for one model
    orientation, any stock model that ever diverged between a contributor's
    install and the mirror would render rotated for one viewer and not
    another. This is the source-nondeterminism behind the U19 confusion in #55.
    Repoint every stock ref ${KICAD10_3DMODEL_DIR}/ -> ${KIPRJMOD}/3d/kicad-stock/
    across t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
    [TAPRX-888.kicad_pcb]
2026-08-22 remove old 3d model pointer correction in mechanical CI, shift status LED hole down 0.5mm in rear endplate
    [endplate-rear.kicad_pcb]
2026-08-22 fix no-connect pin warnings by adding nc pins to U4, U11, U14
    [TAPRX-888.kicad_pcb, TAPRX-888.kicad_sch, refclk.kicad_sch]
2026-08-22 fix LTC2208 reference text error in library
    [TAPRX-888.kicad_pcb]
2026-08-22 add missing schematic parity check from DRC CI checking
2026-08-23 create seperate power symbols to symbol updates may be done with all checks enabled
    [TAPRX-888.kicad_sch, refclk.kicad_sch]
2026-08-23 clean baked-in field junk; strip footprint LCSC; sync board
    - board + schematic: clear Datasheet fields holding stray LCSC numbers,
    fix U8 doubled #PBF MPN
    - library footprints: empty baked-in LCSC Part # (authoritative on the
    schematic; blocks Update-Footprints from clobbering board part numbers)
    - Update PCB from Schematic sync (U8 LCSC, TP exclude-from-pos)
    ERC clean; DRC clean with schematic parity.
    [Front_End.kicad_sch, TAPRX-888.kicad_pcb, TAPRX-888.kicad_sch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]
2026-08-23 normalize fab attributes on non-BOM footprints (mounting holes, logo, TP-Tiny)
2026-08-23 Bring over ringof/dev: design + 3D + mechanical/viewer + CI (#58)
    * throwaway: exercise design -> dev pipeline (safe to delete)
    * Bring over ringof/dev (tranche 2, stage 1): design, library, 3D, board CI & docs
    * Bring over ringof/dev (tranche 2, stage 2): mechanical enclosure + 3D viewer
    * run_checks: hard-fail the 3D-model check regardless of ENFORCE
    * Improved 3D viewer (#59)
    unchanged. This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
    [BUTTON-4p5X4p5.step, Front_End.kicad_sch, LED_RGB_SIDE.step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]
2026-08-23 fix: mechanical-build.yml — move stray make_3d_viewer args back into the step (unbreaks dev-release) (#63)
2026-08-23 3d viewer: stamp board design commit on silk + header, single-source the hash (#65)
2026-08-23 Dev fab githash (#66)
    * inject_provenance: sync board-embedded GIT_HASH property so gerbers stamp the real commit
    * dev-release: trigger on fab-pipeline scripts (parity with main/endplate-release)
    ---------
2026-08-29 mechanical: add scripted GND shield pour + stitching-via ring tool for end plates
2026-08-29 mechanical: updated scripting to handle copper pullbacks for SMA and mask pullbacks for screws
    [endplate-front.kicad_pcb, endplate-rear.kicad_pcb]
2026-08-30 board contraints set for basic DRC checks, excluding isolated copper fill errors ('phantom' because there is no schematic/netlist)
2026-08-30 text size/location adjustments to improve readability
    [endplate-front.kicad_pcb, endplate-rear.kicad_pcb]
2026-08-30 update design and fab notes text on PCB drawings
    [endplate-front.kicad_pcb, endplate-rear.kicad_pcb]
2026-08-30 user.comments text position and nit correction
    [endplate-front.kicad_pcb, endplate-rear.kicad_pcb]
2026-08-30 front panel text changes, shift logos down
    [endplate-front.kicad_pcb]
2026-08-30 endplates: framed fab drawing via KiBot pcb_print (#68)
    Replace the two-call kicad-cli + pdfunite fab-drawing stitch with a single
    KiBot pcb_print pass in build_endplates.sh:
    - correct multi-page title block (Sheet n of N) instead of every page '1 of 1'
    - top page + mirrored bottom page; notes on the top page only (no backwards text)
    - per-layer colours (black outline, blue silk, green notes, orange drawings),
    theme reddish frame retained
    - 1:1 scale so the plate sits clear of the title block
    Point the shared TAPR.kicad_wks Sheet field at ${SHEETNAME} (was ${SHEETPATH},
    empty for PCB-only plates) so each page names its side; the flat 1-level
    schematic hierarchy makes name == path there.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
2026-08-30 adding perimeter stitching for USB, SMA cutouts
    [endplate-front.kicad_pcb, endplate-rear.kicad_pcb]
2026-08-30 fab comments block updated
    [endplate-front.kicad_pcb]
2026-09-07 end-plate GND shield, DRC, and fab notes (#69)
    unchanged. This makes the plates ex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
    [endplate-front.kicad_pcb, endplate-rear.kicad_pcb]
2026-09-07 endplate fab drawing: board-realistic composite + drill-map page (#70)
    * endplate fab drawing: show copper as a translucent wash
    Add F.Cu/B.Cu as the bottom layer on each pcb_print page, in a light
    translucent copper (#C8823C55), so the GND pour, stitch-via rings, and SMA
    keepout voids are visible on the fab drawing while the outline, silk, and
    notes stay legible on top. Drawn first (underneath); the alpha keeps it a
    wash rather than a flood.
    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
2026-09-08 Raise silkscreen line widths to JLCPCB 0.153 mm minimum (#71)
    Library.pretty: 26 footprints, 56 F.SilkS/B.SilkS graphic elements bumped
    0.12/0.1 -> 0.153 (logos TIS-Logo, HamSCI-25mm, TAPR 10mm skipped as filled
    artwork). Board: placed-footprint silk updated from library (382 elements);
    9 board-level graphics (5 F.SilkS pointers, 4 B.SilkS power-label boxes)
    raised to 0.153. .kicad_pro silk_line_width default 0.1 -> 0.153.
    Silk-width criterion of #71 only; silk-to-pad clearance, mask slivers and
    thermal-pad paste apertures remain.
    [TAPRX-888.kicad_pcb]
2026-09-19 Drop chip-passive body silk to clear silk-to-silk violations (#71) and fix silk widths to JLCPCB requirements
    [TAPRX-888.kicad_pcb]
2026-09-20 tweaks to mask design rules
    [TAPRX-888.kicad_pcb]
2026-09-20 making JLCDFM happy pt. 1
    [TAPRX-888.kicad_pcb]
2026-10-21 Document advanced-tier rationale + JLC DFM triage in DRU header
    U11 EZ-USB FX3 (121-ball 0.5mm-pitch BGA) forces 0.15mm via drills + 0.05mm
    annular rings (below standard tier); 0.1mm tracks are fine-pitch escape, not
    widenable. 2026-09-19 JLC DFM pass triaged every danger to accept. Comment-only.
2026-10-24 USB diff pair updates to get to 0.155mm W, 0.2mm gap
